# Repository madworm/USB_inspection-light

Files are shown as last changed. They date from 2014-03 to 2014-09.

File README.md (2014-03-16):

USB inspection-light
====================

LAYOUT FILES: USB powered inspection light for tight places.

USB inspection-light

You will find code for this project in [this](https://github.com/madworm/ATtiny_projects) repository.

---

Before having PC-boards made, please make sure you know about your manufacturer's peculiarities!
Especially drill-sizes and their tolerances may vary too much and give you trouble.

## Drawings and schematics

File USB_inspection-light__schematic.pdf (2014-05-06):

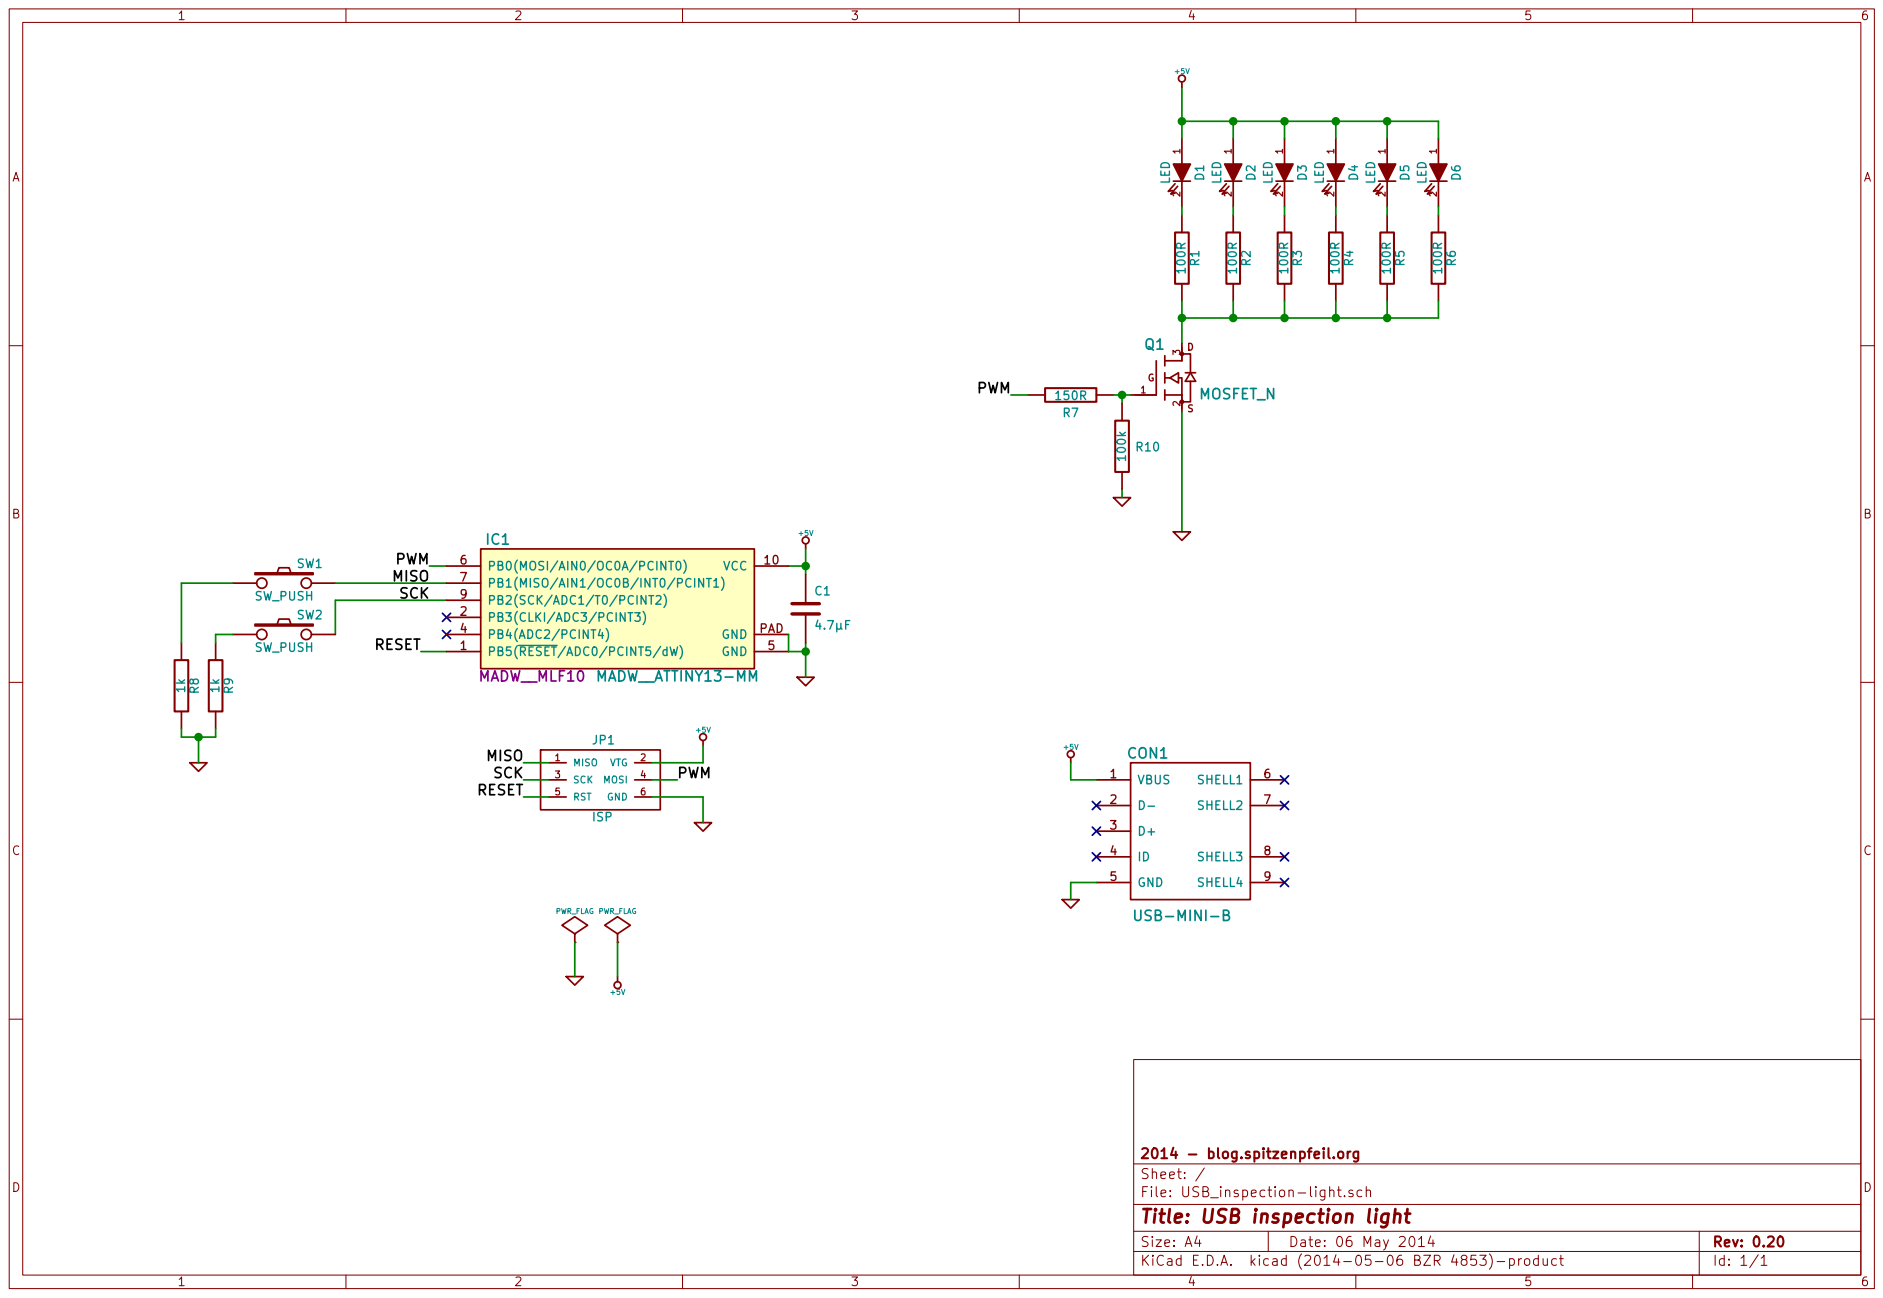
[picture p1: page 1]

File: USB_inspection-light.sch Sheet: / 2014 - blog.spitzenpfeil.org

Id: 1/1 Title: USB inspection light

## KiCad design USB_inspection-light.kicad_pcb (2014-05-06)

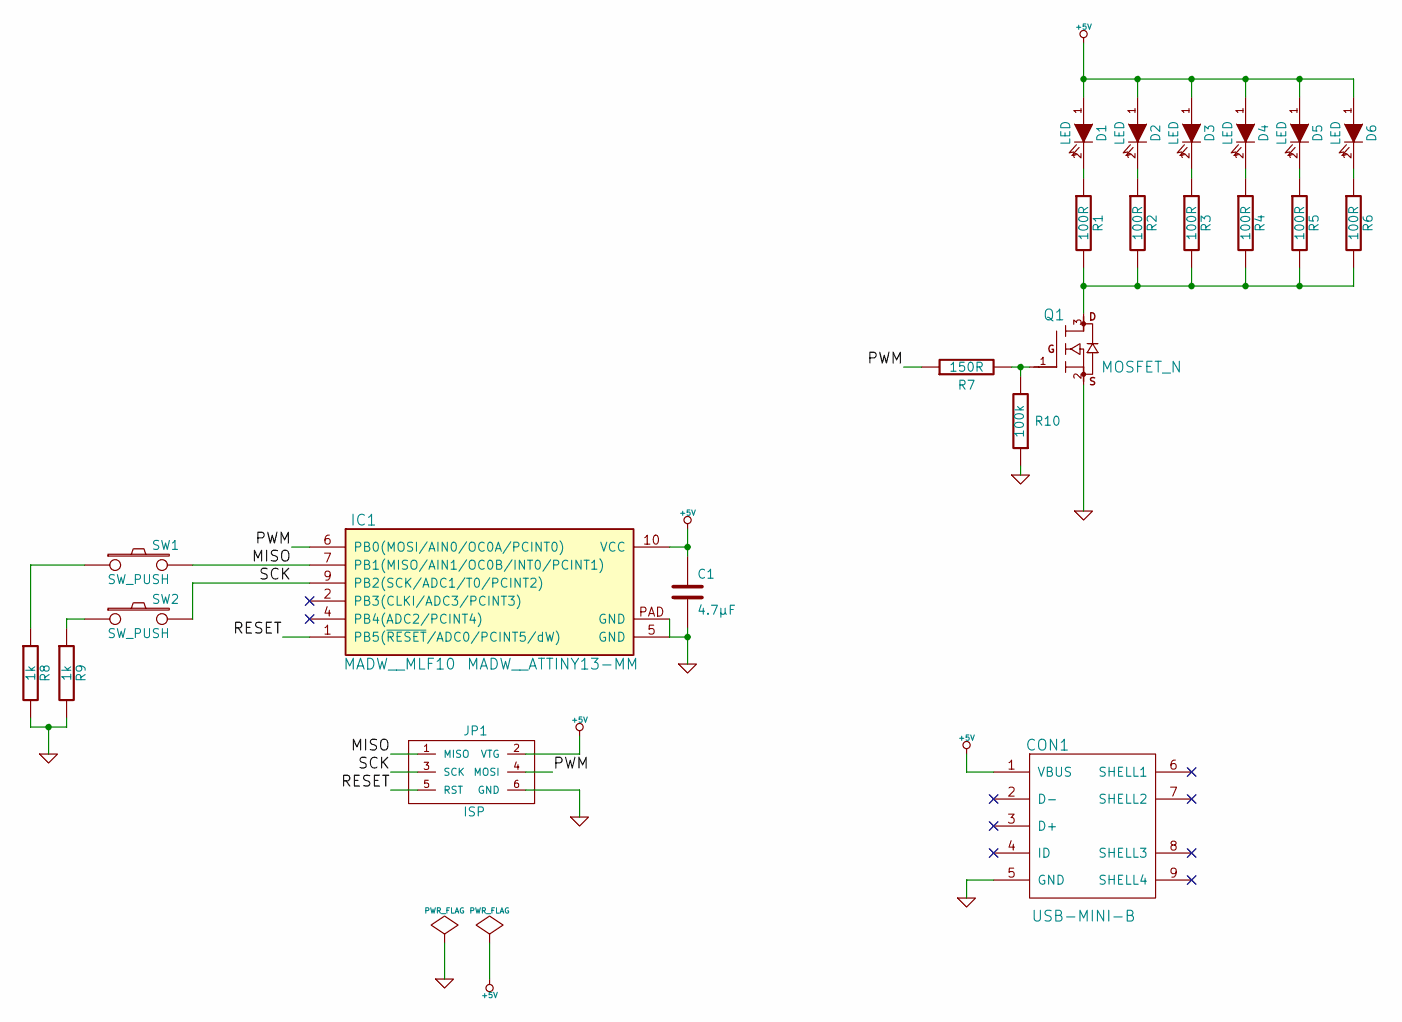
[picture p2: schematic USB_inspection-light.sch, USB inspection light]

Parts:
C1: 4.7µF
CON1: USB-MINI-B
D1, D2, D3, D4, D5, D6: LED
IC1: MADW__ATTINY13-MM; MADW__MLF10
JP1: ISP
Q1: MOSFET_N
R1, R2, R3, R4, R5, R6: 100R
R7: 150R
R8, R9: 1k
R10: 100k
SW1, SW2: SW_PUSH

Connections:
+5V: C1.1, CON1.1 (VBUS), D1.1 (A), D2.1 (A), D3.1 (A), D4.1 (A), D5.1 (A), D6.1 (A), IC1.10 (VCC), JP1.2 (VTG)
/MISO: IC1.7 (PB1(MISO/AIN1/OC0B/INT0/PCINT1)), JP1.1 (MISO), SW1.2
/PWM: IC1.6 (PB0(MOSI/AIN0/OC0A/PCINT0)), JP1.4 (MOSI), R7.1
/RESET: IC1.1 (PB5(~RESET~/ADC0/PCINT5/dW)), JP1.5 (RST)
/SCK: IC1.9 (PB2(SCK/ADC1/T0/PCINT2)), JP1.3 (SCK), SW2.2
GND: C1.2, CON1.5 (GND), IC1.5 (GND), IC1.PAD (GND), JP1.6 (GND), Q1.2 (S), R8.2, R9.2, R10.1
unnamed: D1.2 (K), R1.1
unnamed: D2.2 (K), R2.1
unnamed: D3.2 (K), R3.1
unnamed: D4.2 (K), R4.1
unnamed: D5.2 (K), R5.1
unnamed: D6.2 (K), R6.1
unnamed: Q1.1 (G), R7.2, R10.2
unnamed: Q1.3 (D), R1.2, R2.2, R3.2, R4.2, R5.2, R6.2
unnamed: R8.1, SW1.1
unnamed: R9.1, SW2.1

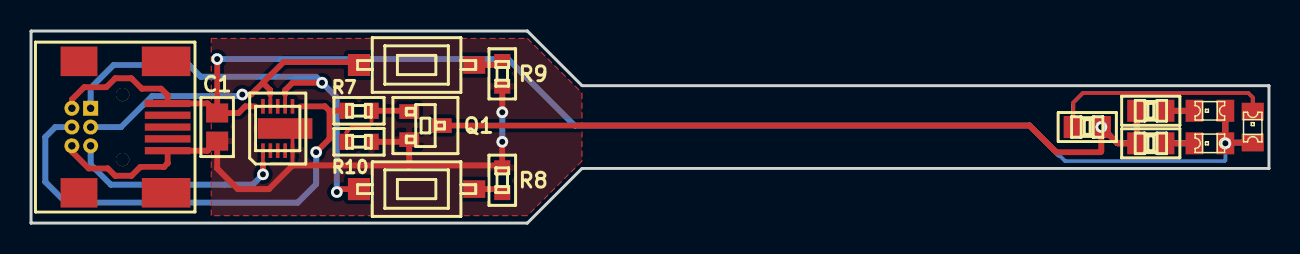
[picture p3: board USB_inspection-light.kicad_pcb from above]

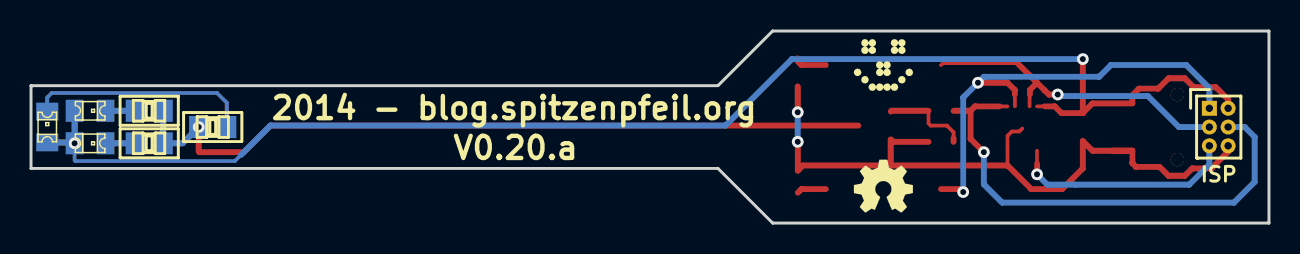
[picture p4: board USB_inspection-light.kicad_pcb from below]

Board: 2 copper layers, 83.8 x 13.0 mm, 25 parts (9 on the bottom side), 16 nets.

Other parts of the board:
G1: OSHW-logo_silkscreen_4mm
G2: LED_smile_silkscreen_4mm

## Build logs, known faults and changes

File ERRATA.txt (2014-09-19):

Pre V0.20 boards:
-----------------

You may want to place a 100k pull-down resistor across gate & source of
the MOSFET transistor. These are the 2 pins pointing towards the USB
connector.

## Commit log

2014-02-23 Added 3D shapes.
    Thanks to: http://smisioto.no-ip.org/elettronica/kicad/kicad-en.htm
    [USB_inspection-light.kicad_pcb]
2014-03-02 Added a GND plane on F_Cu. Just for fun.
    [USB_inspection-light-B_Cu.gbl, USB_inspection-light-B_Mask.gbs, USB_inspection-light-B_SilkS.gbo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]
2014-03-03 GND plane tweaks.
    [USB_inspection-light-B_Cu.gbl, USB_inspection-light-B_Mask.gbs, USB_inspection-light-B_SilkS.gbo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]
2014-03-14 Adapted board outline to changed usb socket footprint outline.
    [USB_inspection-light-B_Cu.gbl, USB_inspection-light-B_Mask.gbs, USB_inspection-light-B_SilkS.gbo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]
2014-03-16 Switched SOT23 footprint to my own library. Silkscreen issue.
    [USB_inspection-light.kicad_pcb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]
2014-03-18 Tweaks: incr. trace-width, ISP header, copper pour.
    [USB_inspection-light-B_Cu.gbl, USB_inspection-light-B_Mask.gbs, USB_inspection-light-B_SilkS.gbo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]
2014-05-06 Added 100k pull-down resistor to mosfet gate.
    Purpose: prevent LED flash on power-up.
    [USB_inspection-light.kicad_pcb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]
2014-05-27 Updated 'gerber_files/make_all-pngs.sh'.
